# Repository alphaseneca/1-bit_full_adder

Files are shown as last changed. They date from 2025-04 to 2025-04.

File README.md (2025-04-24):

# Full Adder

## Overview

A **1-bit Full Adder** is a basic circuit used to add three input bits: two data bits (**A** and **B**) and a carry-in bit (**Cin**).

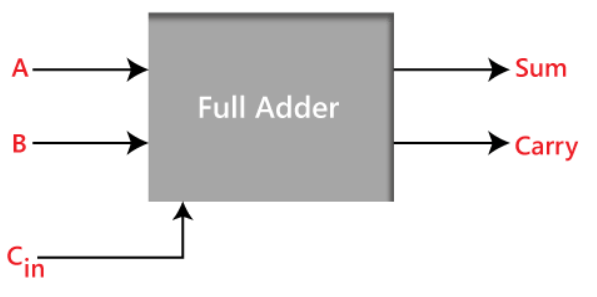
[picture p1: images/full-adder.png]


It produces two outputs:

- **Sum**: The result of the addition.
- **Carry (Cout)**: The carry passed to the next bit in case of multi-bit additions.

This circuit plays an important role in digital electronics and serves as the foundation for larger systems like multi-bit adders used in microprocessors.

## Design and Implementation

### Initial Plan

At first, I followed the typical textbook design, which uses:

- **2 XOR gates**
- **2 AND gates**
- **1 OR gate**

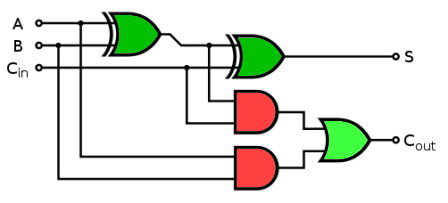
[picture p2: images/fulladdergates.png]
    

This approach worked, but it required more transistors than I expected. Every gate used multiple transistors, so the total count grew quickly.

### Optimized Approach

To make it simpler, I tried using **only NOR gates**. This reduced the number of components, and I was able to build the adder using just **9 transistors**. It was a good way to explore how small changes can make a big difference in circuit design.

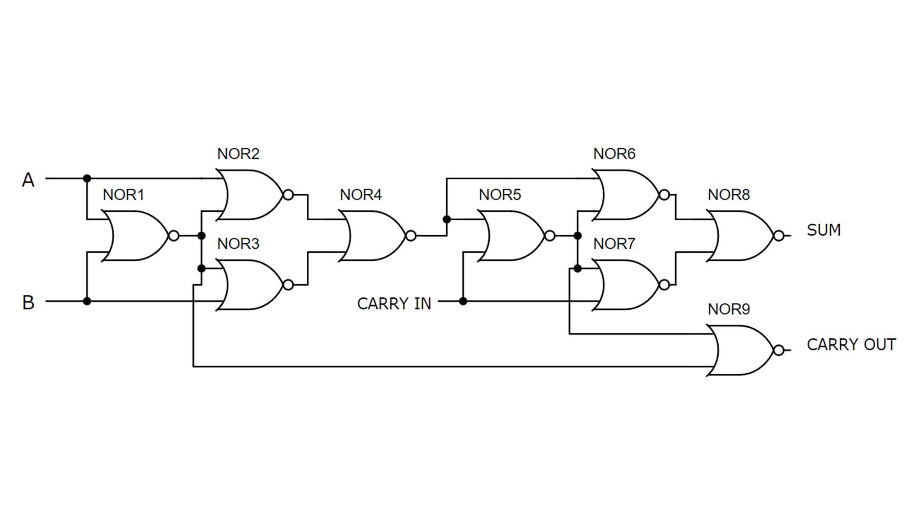
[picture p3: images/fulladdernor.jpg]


## Truth Table

    Sum: A ⊕ B ⊕ Cin
    Carry (Cout): (A · B) + (Cin · (A ⊕ B))

| **A** | **B** | **Cin** | **Sum** | **Cout** |
| :---: | :---: | :-----: | :-----: | :---: |
| 0 | 0 | 0 | 0 | 0 |
| 0 | 0 | 1 | 1 | 0 |
| 0 | 1 | 0 | 1 | 0 |
| 0 | 1 | 1 | 0 | 1 |
| 1 | 0 | 0 | 1 | 0 |
| 1 | 0 | 1 | 0 | 1 |
| 1 | 1 | 0 | 0 | 1 |
| 1 | 1 | 1 | 1 | 1 |

---

## My Design Journey

I first got the idea for this project in my **Digital Logics** class, where we learned about logic gates and how they are built. I thought it would be fun and helpful to build a real circuit and see how the gates work together. I had already made a schematic of the prototype earlier, but the final version came together during **Workshop 101** by **LAB448** at **Pashchimanchal Campus**.



## PCB

After the success of the prototype, I decided to make a PCB for the adder. This pcb is designed to be used as a module to make the student understand the concept of full adder.

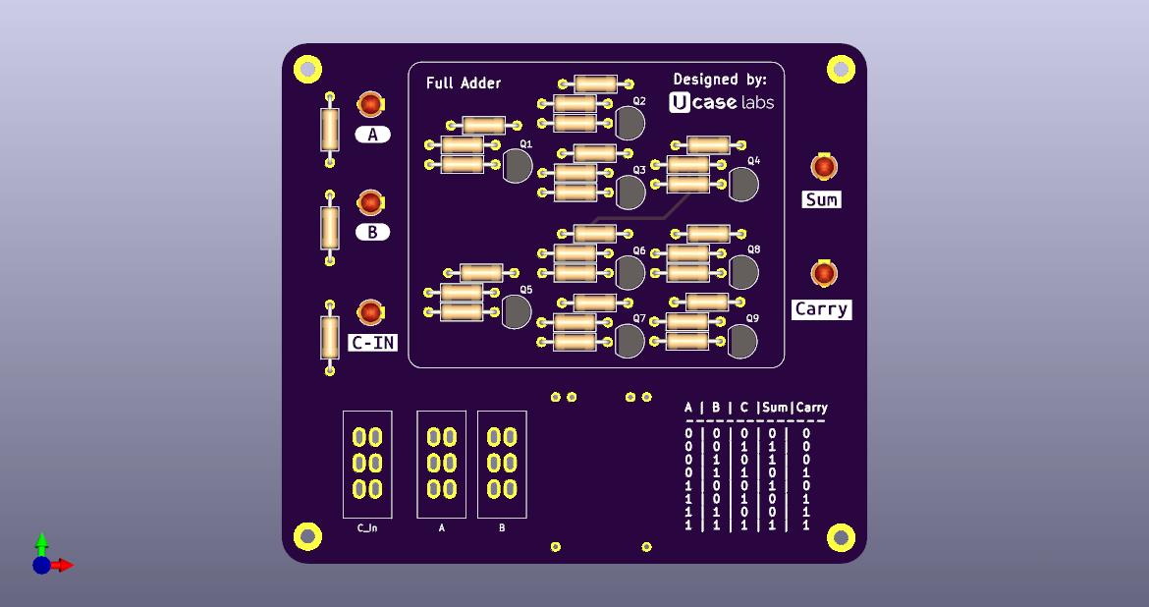
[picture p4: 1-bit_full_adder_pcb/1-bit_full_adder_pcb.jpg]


---

## References

- [9 transistor full adder [YouTube]](https://www.youtube.com/watch?v=DtL7BKjrqFo)
- [Fundamental of TTL gates](http://hyperphysics.phy-astr.gsu.edu/hbase/Electronic/trangate.html)

This repository not only tracks the **1-bit Full Adder** but also keeps a record of my progress and future updates. It will serve as a reference for new experiments and improvements.

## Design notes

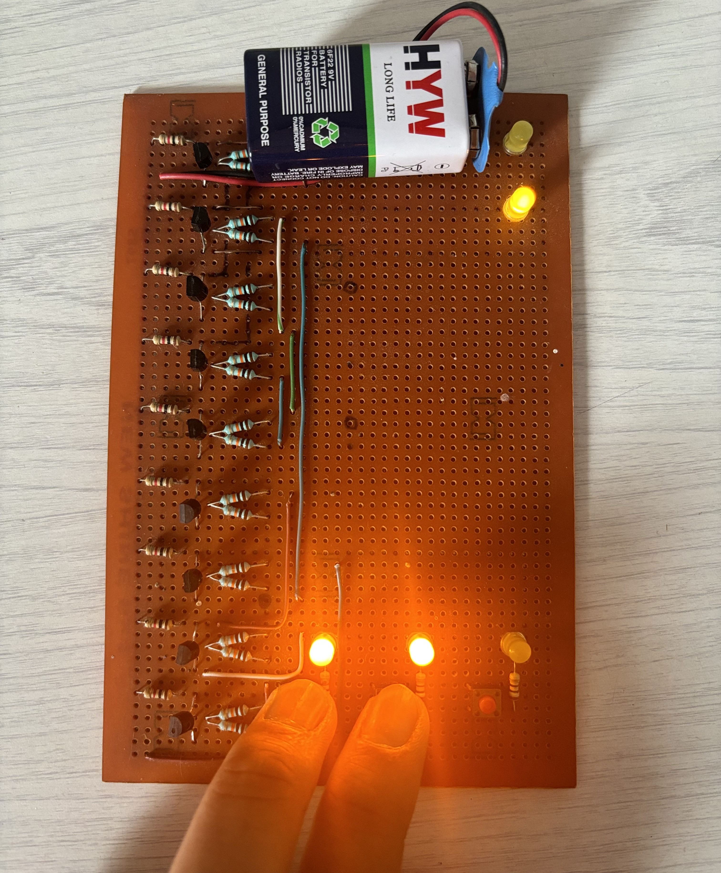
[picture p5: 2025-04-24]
images/fulladder (3).jpg

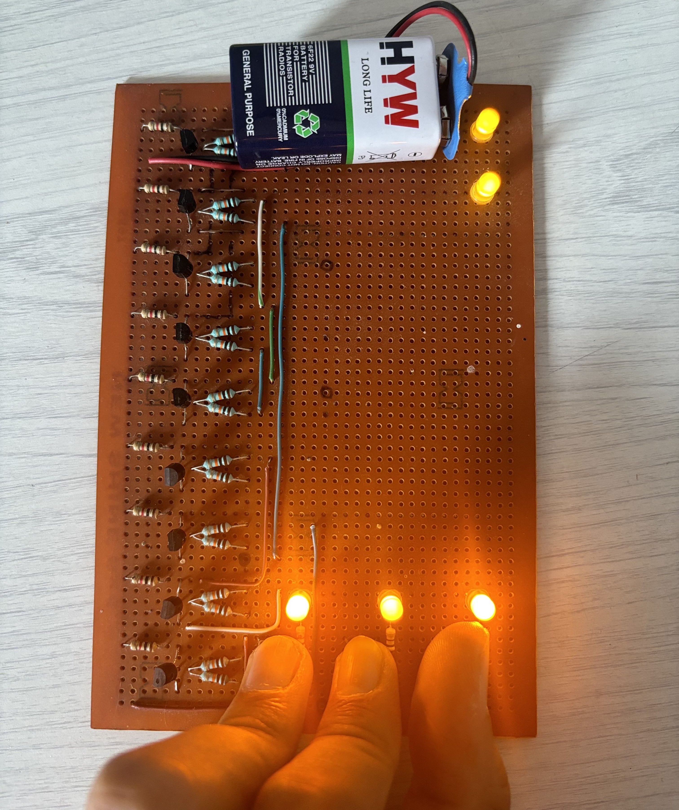
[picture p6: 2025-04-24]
images/fulladder (1).jpg

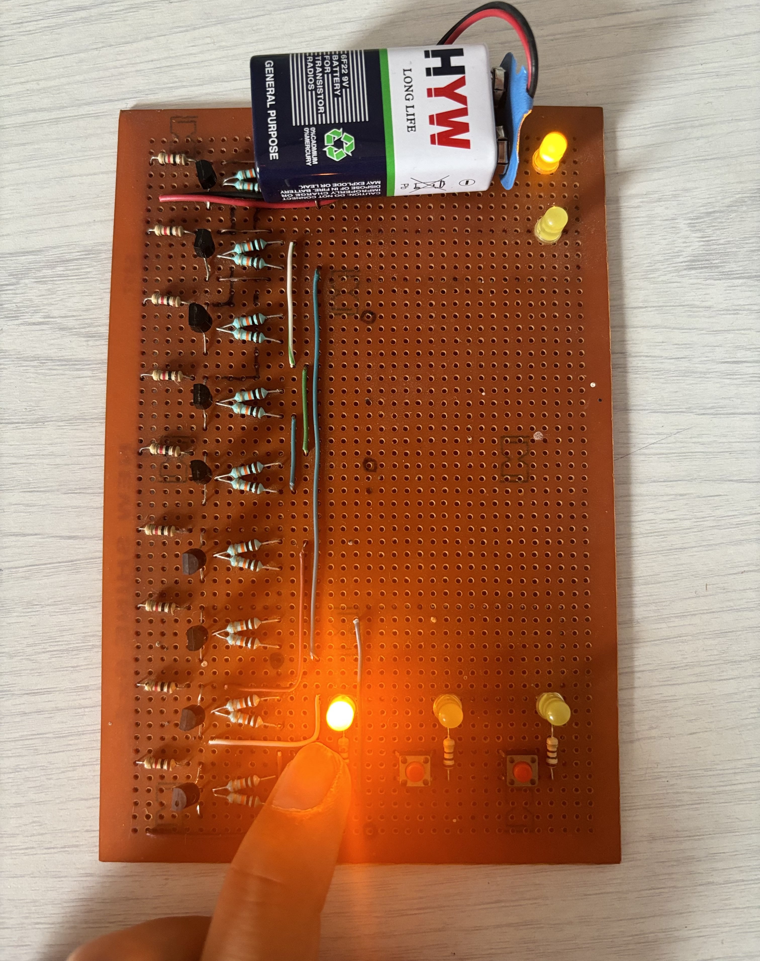
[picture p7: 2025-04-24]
images/fulladder (2).jpg

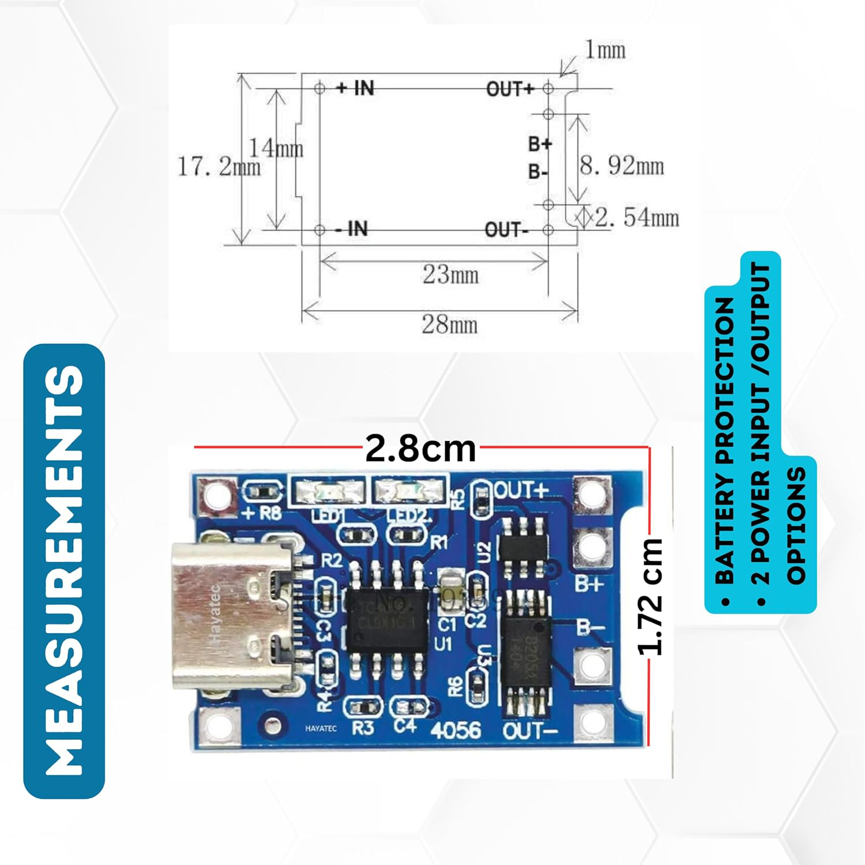
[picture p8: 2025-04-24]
1-bit_full_adder_pcb/714CW2NPVqL._AC_SL1500_.jpg

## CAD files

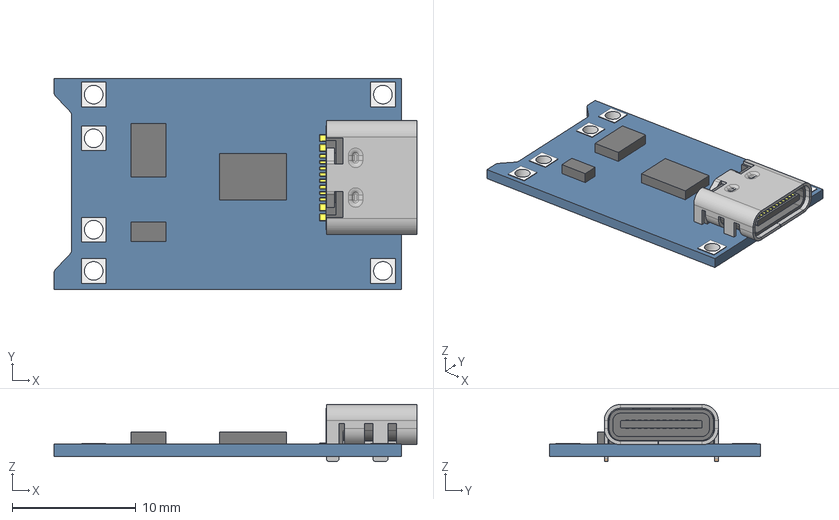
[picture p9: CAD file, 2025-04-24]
1-bit_full_adder_pcb/tp4056/TP4056--3DModel-STEP-684600.STEP
29.3 x 17.0 x 4.60 mm

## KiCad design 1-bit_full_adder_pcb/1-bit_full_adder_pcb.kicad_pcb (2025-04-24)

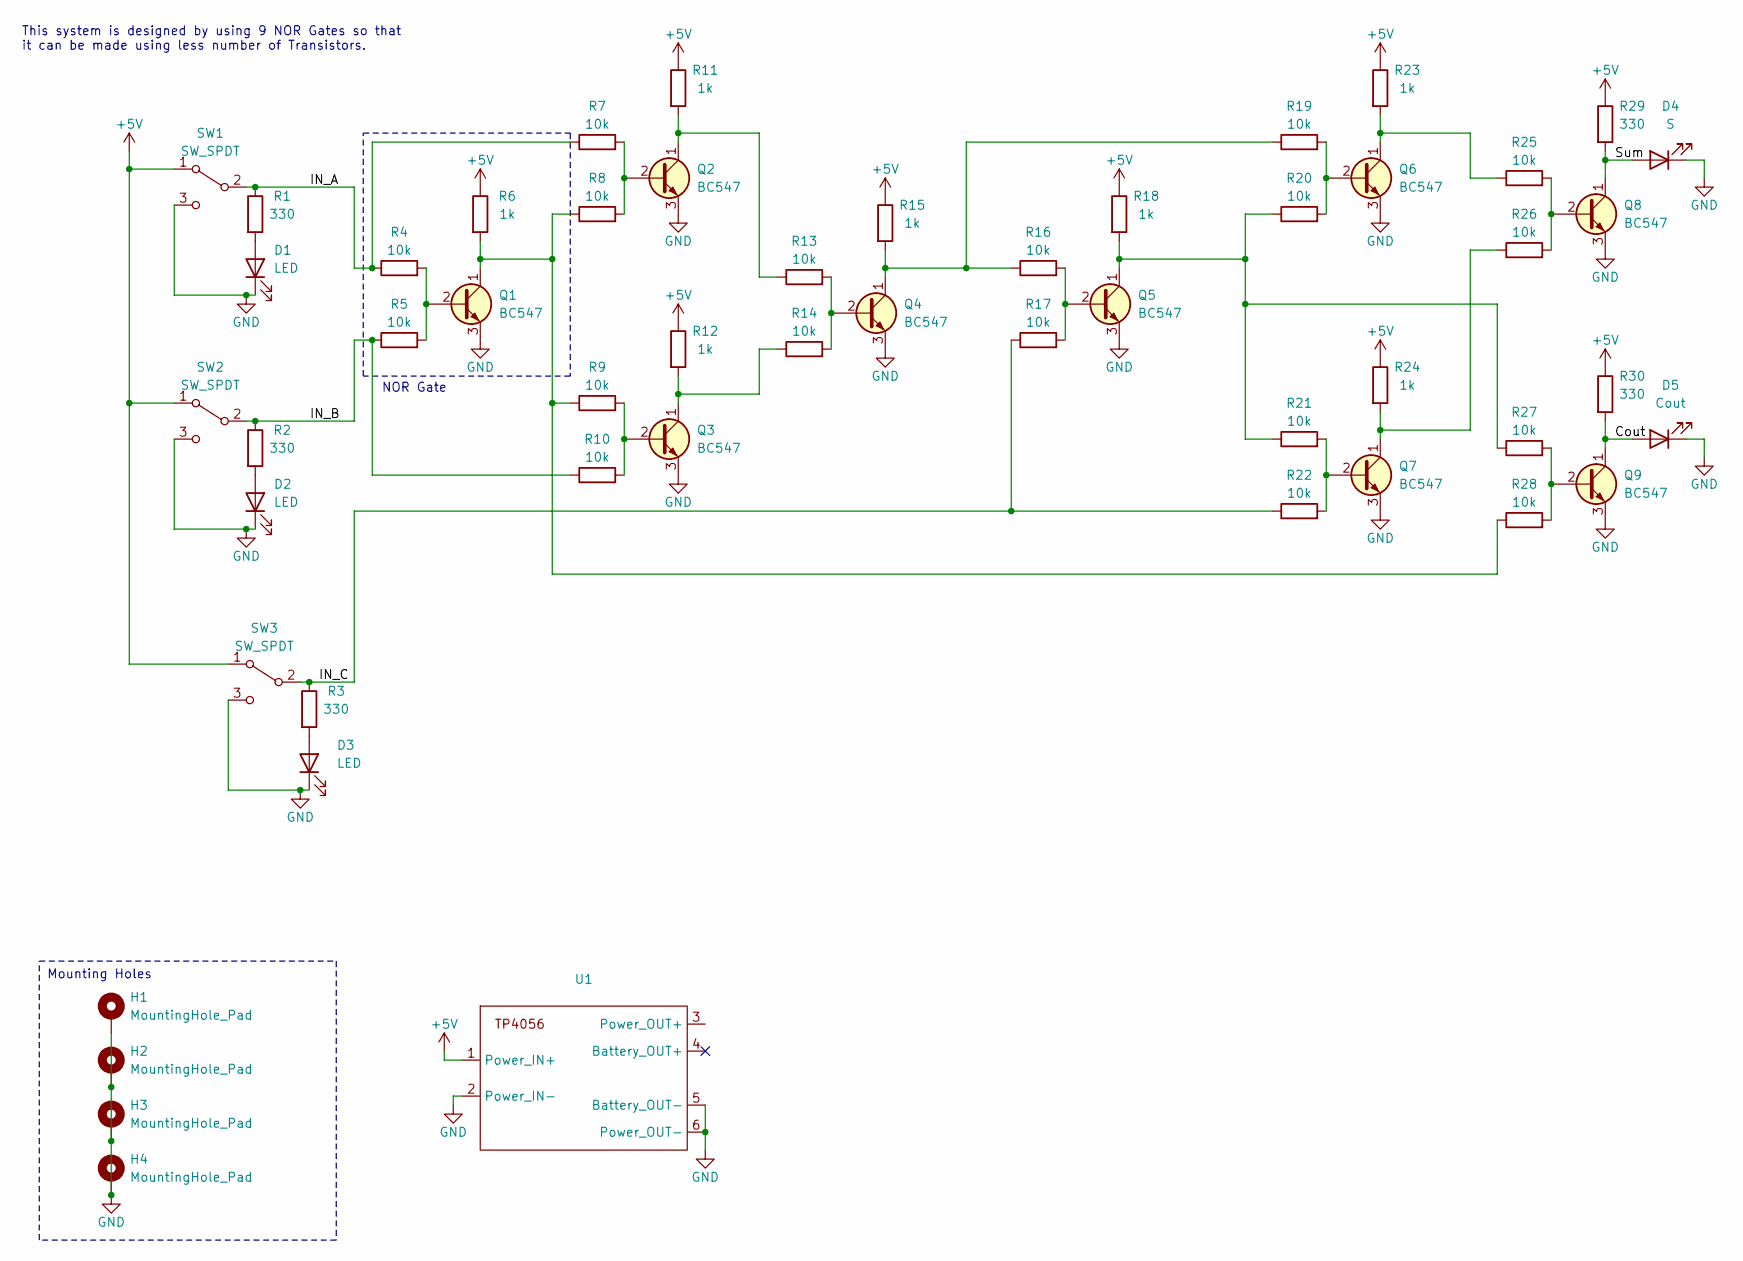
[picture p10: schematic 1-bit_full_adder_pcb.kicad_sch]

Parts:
D1, D2, D3: LED; LED_D3.0mm
D4: S; LED_D3.0mm
D5: Cout; LED_D3.0mm
H1, H2, H3, H4: MountingHole_Pad; MountingHole_2.2mm_M2_Pad_TopBottom
Q1, Q2, Q3, Q4, Q5, Q6, Q7, Q8, Q9: BC547; TO-92_Inline_CBE
R1, R2, R3, R29, R30: 330; R_Axial_DIN0207_L6.3mm_D2.5mm_P10.16mm_Horizontal
R4, R5, R7, R8, R9, R10, R13, R14, R16, R17, R19, R20, R21, R22, R25, R26, R27, R28: 10k; R_Axial_DIN0207_L6.3mm_D2.5mm_P10.16mm_Horizontal
R6, R11, R12, R15, R18, R23, R24: 1k; R_Axial_DIN0207_L6.3mm_D2.5mm_P10.16mm_Horizontal
SW1, SW2, SW3: SW_SPDT; SWITCH_S20203
U1: tp4056_module

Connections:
+5V: R6.1, R11.1, R12.1, R15.1, R18.1, R23.1, R24.1, R29.1, R30.1, SW1.1 (A), SW2.1 (A), SW3.1 (A), U1.1 (Power_IN+); also elsewhere on the board
/Cout: D5.2 (A), Q9.1 (C), R30.2
/IN_A: R1.1, R4.1, R7.1, SW1.2 (B); also elsewhere on the board
/IN_B: R2.1, R5.1, R10.1, SW2.2 (B); also elsewhere on the board
/IN_C: R3.1, R17.1, R22.1, SW3.2 (B); also elsewhere on the board
/Sum: D4.2 (A), Q8.1 (C), R29.2
GND: D1.1 (K), D2.1 (K), D3.1 (K), D4.1 (K), D5.1 (K), H1.1, H2.1, H3.1, H4.1, Q1.3 (E), Q2.3 (E), Q3.3 (E), Q4.3 (E), Q5.3 (E), Q6.3 (E), Q7.3 (E), Q8.3 (E), Q9.3 (E), SW1.3 (C), SW2.3 (C), SW3.3 (C), U1.2 (Power_IN-), U1.5 (Battery_OUT-), U1.6 (Power_OUT-); also elsewhere on the board
unnamed: D1.2 (A), R1.2
unnamed: D2.2 (A), R2.2
unnamed: D3.2 (A), R3.2
unnamed: Q1.2 (B), R4.2, R5.2
unnamed: Q1.1 (C), R6.2, R8.1, R9.1, R28.1
unnamed: Q2.2 (B), R7.2, R8.2
unnamed: Q2.1 (C), R11.2, R13.1
unnamed: Q3.2 (B), R9.2, R10.2
unnamed: Q3.1 (C), R12.2, R14.1
unnamed: Q4.2 (B), R13.2, R14.2
unnamed: Q4.1 (C), R15.2, R16.1, R19.1
unnamed: Q5.2 (B), R16.2, R17.2
unnamed: Q5.1 (C), R18.2, R20.1, R21.1, R27.1
unnamed: Q6.2 (B), R19.2, R20.2
unnamed: Q6.1 (C), R23.2, R25.1
unnamed: Q7.2 (B), R21.2, R22.2
unnamed: Q7.1 (C), R24.2, R26.1
unnamed: Q8.2 (B), R25.2, R26.2
unnamed: Q9.2 (B), R27.2, R28.2

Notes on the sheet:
Mounting Holes
NOR Gate
This system is designed by using 9 NOR Gates so that it can be made using less number of Transistors.

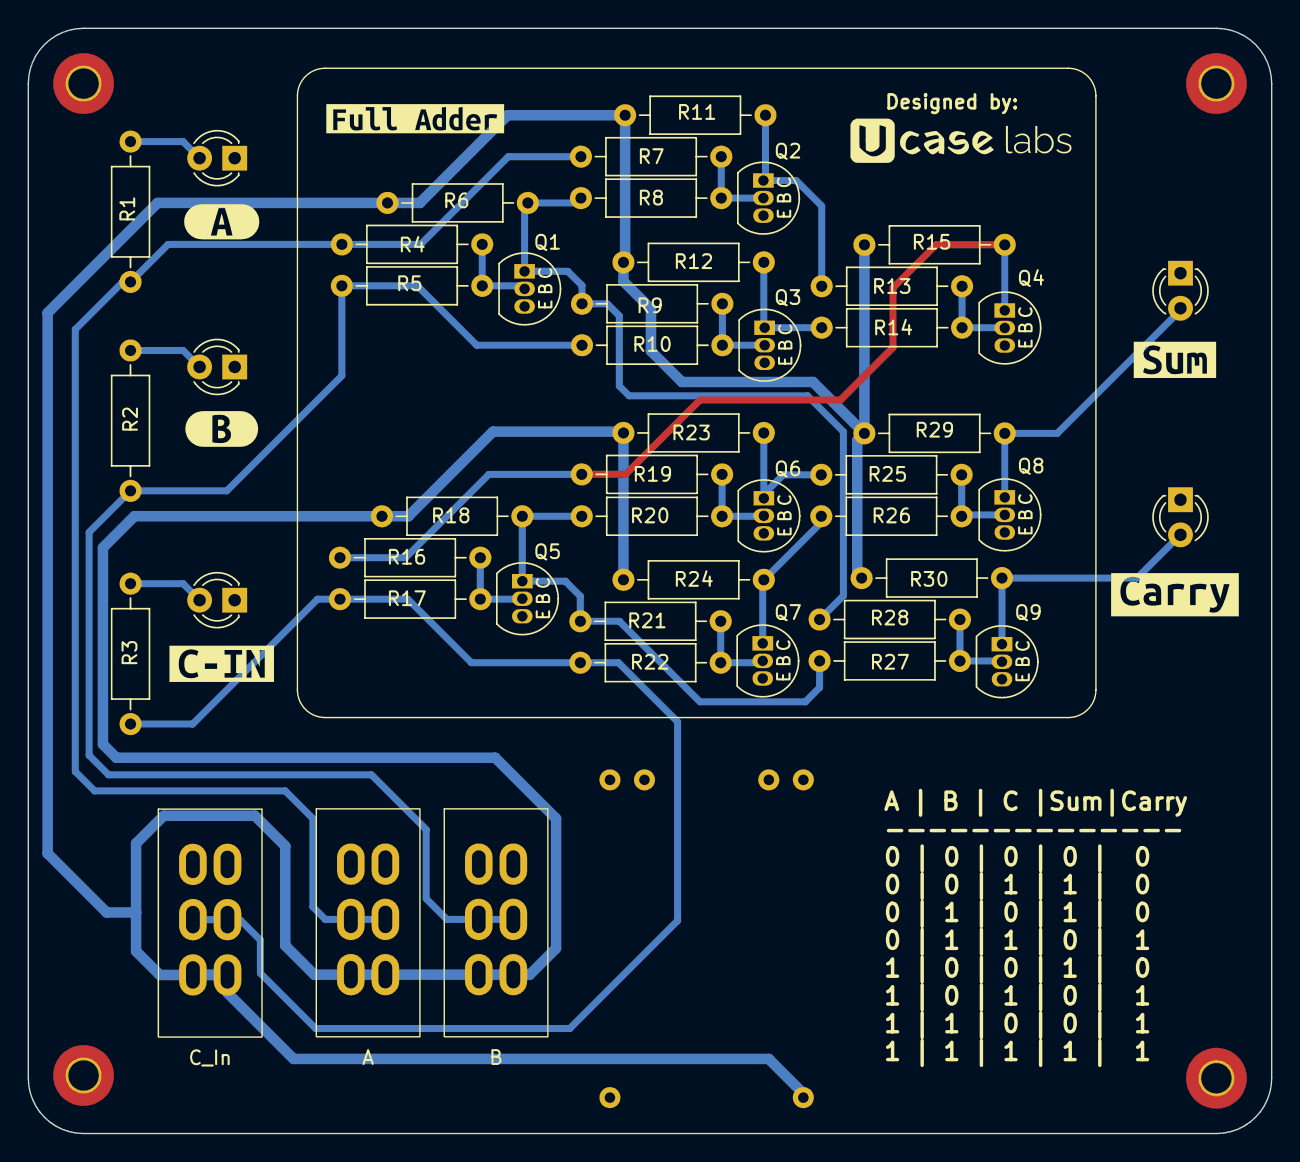
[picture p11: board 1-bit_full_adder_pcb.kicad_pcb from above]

Board: 2 copper layers, 90.0 x 80.0 mm, 58 parts (1 on the bottom side), 26 nets.

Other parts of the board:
A: SW_SPDT; SWITCH_S20203
B: SW_SPDT; SWITCH_S20203
C_In: SW_SPDT; SWITCH_S20203
kibuzzard-67192DAB: G***; kibuzzard-67192DAB
kibuzzard-67192DB9: G***; kibuzzard-67192DB9
kibuzzard-67192E28: G***; kibuzzard-67192E28
kibuzzard-67192E40: G***; kibuzzard-67192E40
kibuzzard-67192E50: G***; kibuzzard-67192E50
kibuzzard-6724957C: G***; kibuzzard-6724957C

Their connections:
+5V: A.1 (A), B.1 (A), C_In.1 (A); also elsewhere on the board
/IN_A: A.2 (B); also elsewhere on the board
/IN_B: B.2 (B); also elsewhere on the board
/IN_C: C_In.2 (B); also elsewhere on the board
GND: A.3 (C), B.3 (C), C_In.3 (C); also elsewhere on the board
